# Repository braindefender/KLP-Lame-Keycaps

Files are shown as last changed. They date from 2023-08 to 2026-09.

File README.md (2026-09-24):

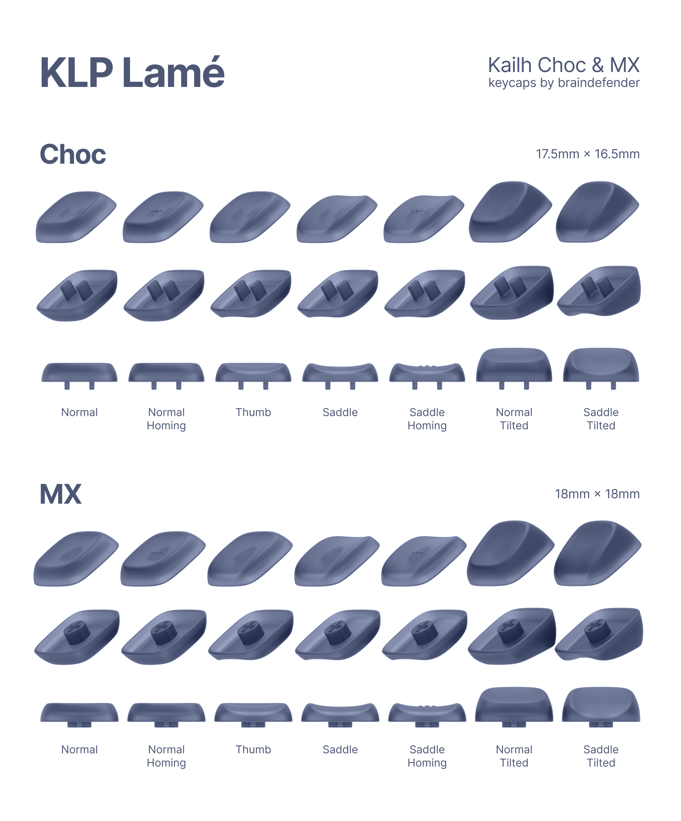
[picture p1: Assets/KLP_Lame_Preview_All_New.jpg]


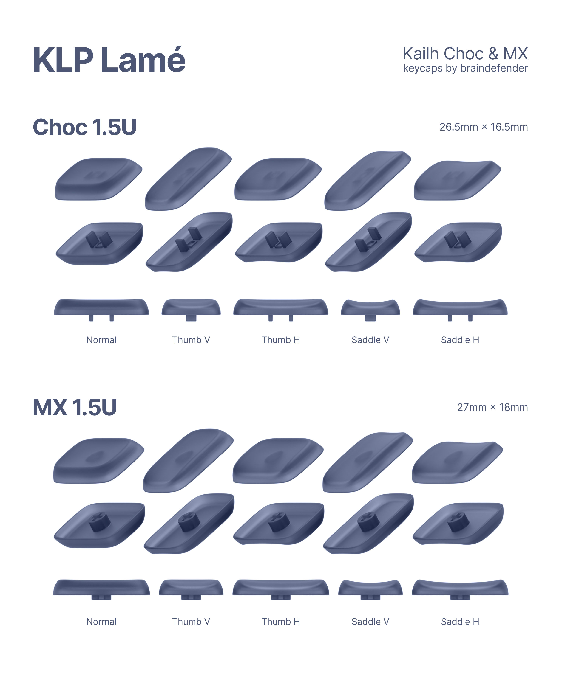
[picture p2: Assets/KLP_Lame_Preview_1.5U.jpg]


# KLP Lamé — Kailh Choc & MX Keycaps

Sculpted and curved keycaps for Kailh Choc and MX switches. Here is a project structure:

| Folder | Description |
| :--- | :--- |
| **Assets** | Various images and actual photos of keycaps |
| **Blender** | Blender files for preview image render |
| **Fusion 360** | Source files for [Autodesk Fusion 360](https://www.autodesk.com/products/fusion-360/overview) |
| **Production** | Combined STL 3D models suitable for 3D-Printing services (like [JLC3DP](https://jlc3dp.com))  |
| **STEP** | 3D models in STEP format for any CAD or Slicer software |
| **STL** | 3D models in STL format for any CAD or Slicer software |

> `STEP` and `STL` folders contain all combinations of Choc/MX Stem + Choc/MX Size.
>
> There is also `90 deg Rotated` variants for Choc Stem.

There are currently 7 variants of 1U keycaps:
| Variant | Description |
| :--- | :--- |
| **Normal** | Just a flat keycap profile with a small recess, that is soothing for fingers |
| **Normal Tilted** | Same as Normal, but top profile has a 15° tilt and 0.5mm upward height compensation |
| **Normal Homing** | Has three little bumps that is useful to determine home positions |
| **Thumb** | Same as Normal, but top profile has a cut along down side |
| **Saddle** | Same as Thumb, but top profile has two symmetrical cuts |
| **Saddle Tilted** | Tilted version of Saddle. Same 15° and height compensation |
| **Saddle Homing** | Has three little bumps that is useful to determine home positions |

And also 5 variants of 1.5U keycaps:
| Variant | Description |
| :--- | :--- |
| **Normal** | Just a flat keycap profile with a small recess, that is soothing for fingers |
| **Thumb H**  | 1.5U variant of Thumb. Horizontal |
| **Thumb V**  | 1.5U variant of Thumb. Vertical (stem is rotated) |
| **Saddle H** | 1.5U variant of Saddle. Horizontal |
| **Saddle V** | 1.5U variant of Saddle. Vertical (stem is rotated) |

## What keycaps do I need for my keyboard?

First, you should choose Choc/MX stem (depends of your switches)<br>
Second, choose Choc/MX size that is suitable for your keyboard.<br>
Then, pick what keycap variants you want for your columns/rows/thumbs. It depends entirely of your choice.

For corne-like keyboards with 36-keys I use:

| Amount | Kind | Purpose |
| -----: | :--- | :--- |
| 20 | Saddle Tilted | For top and bottom rows |
| 16 | Saddle | For home row + 6 for thumbs |

or

| Amount | Kind | Purpose |
| -----: | :--- | :--- |
| 20 | Normal Tilted | For top and bottom rows |
| 10 | Normal | For home row |
| 6 | Thumb | For thumbs |

## Where to buy?

> Use middle click or tap & hold to open in new tab

<a href="https://aliexpress.ru/wholesale?SearchText=klp+lame">
  aliexpress.ru
</a>
<a href="https://ergosplits.ru/item/219">
  ergosplits.ru
</a>
<a href="https://fkcaps.com/collections/klp-lame">
  fkcaps.com
</a>
<a href="https://holykeebs.com/products/klp-lame-keycaps">
  holykeebs.com
</a>
<a href="https://www.keebart.com/products/klp-lame-keycaps">
  keebart.com
</a>
<a href="https://keeb.supply/search?q=Lame">
  keeb.supply
</a>
<a href="https://keycapsss.com/KLP-Lame-Ergonomic-Keycaps-Choc/KC10269">
  keycapsss.com
</a>
<a href="https://typeractive.xyz/products/klp-lame-sculpted-keycaps">
  typeractive.xyz
</a>
<a href="https://shop.yushakobo.jp/search?q=Lame">
  yushakobo.jp
</a>
<a href="https://yuzukeycaps.com">
  yuzukeycaps.com
</a>

## How to print?

It is best to position the model more vertically to avoid tactile layer-to-layer bumps. Personally, I use 45° or 75° angle, but it's up to you.

`Production` folder contains files that you can use in any 3D-printing service like [JLC3DP](https://jlc3dp.com) or [PCBWay](https://www.pcbway.com/rapid-prototyping/3d-printing/). You can download them directly using links below:

### Normal

| File | Choc Stem + Choc Size | Choc Stem + MX Size | MX Stem + MX Size | MX Stem + Choc Size | Kinds |
| :--- | :--- | :--- | :--- | :--- | --- |
| Normal Part 1 | [Download][normal-part-1-choc] | [Download][normal-part-1-choc-mx] | [Download][normal-part-1-mx] | [Download][normal-part-1-mx-choc] | - 6 × Normal Tilted<br/>- 3 × Normal |
| Normal Part 2 | [Download][normal-part-2-choc] | [Download][normal-part-2-choc-mx] | [Download][normal-part-2-mx] | [Download][normal-part-2-mx-choc] | - 4 × Normal Tilted<br/>- 3 × Thumb<br/>- 1 × Normal Homing<br/>- 1 × Normal |
| Normal Part 3 | [Download][normal-part-3-choc] | [Download][normal-part-3-choc-mx] | [Download][normal-part-3-mx] | [Download][normal-part-3-mx-choc] | - 9 × Normal Tilted |

### Saddle

| File | Choc Stem + Choc Size | Choc Stem + MX Size | MX Stem + MX Size | MX Stem + Choc Size | Kinds |
| :--- | :--- | :--- | :--- | :--- | --- |
| Saddle Part 1 | [Download][saddle-part-1-choc] | [Download][saddle-part-1-choc-mx] | [Download][saddle-part-1-mx] | [Download][saddle-part-1-mx-choc] | - 6 × Saddle Tilted<br/>- 3 × Saddle |
| Saddle Part 2 | [Download][saddle-part-2-choc] | [Download][saddle-part-2-choc-mx] | [Download][saddle-part-2-mx] | [Download][saddle-part-2-mx-choc] | - 4 × Saddle Tilted<br/>- 4 × Saddle<br/>- 1 × Saddle Homing |
| Saddle Part 3 | [Download][saddle-part-3-choc] | [Download][saddle-part-3-choc-mx] | [Download][saddle-part-3-mx] | [Download][saddle-part-3-mx-choc] | - 9 × Saddle Tilted |

### Thumbs

| File | Choc Stem + Choc Size | Choc Stem + MX Size | MX Stem + MX Size | MX Stem + Choc Size | Kinds |
| :----- | :--- | :--- | :--- | :--- | --- |
| Thumbs | [Download][thumbs-part-1-choc] | [Download][thumbs-part-1-choc-mx] | [Download][thumbs-part-1-mx] | [Download][thumbs-part-1-mx-choc] | - 9 × Thumb |

[normal-part-1-choc]: ./Production/Choc%20Stem%20%2B%20Choc%20Size/Choc_Stem_Choc_Size_Normal_Part_1.zip
[normal-part-2-choc]: ./Production/Choc%20Stem%20%2B%20Choc%20Size/Choc_Stem_Choc_Size_Normal_Part_2.zip
[normal-part-3-choc]: ./Production/Choc%20Stem%20%2B%20Choc%20Size/Choc_Stem_Choc_Size_Normal_Part_3.zip

[normal-part-1-choc-mx]: ./Production/Choc%20Stem%20%2B%20MX%20Size/Choc_Stem_MX_Size_Normal_Part_1.zip
[normal-part-2-choc-mx]: ./Production/Choc%20Stem%20%2B%20MX%20Size/Choc_Stem_MX_Size_Normal_Part_2.zip
[normal-part-3-choc-mx]: ./Production/Choc%20Stem%20%2B%20MX%20Size/Choc_Stem_MX_Size_Normal_Part_3.zip

[normal-part-1-mx]: ./Production/MX%20Stem%20%2B%20MX%20Size/MX_Stem_MX_Size_Normal_Part_1.zip
[normal-part-2-mx]: ./Production/MX%20Stem%20%2B%20MX%20Size/MX_Stem_MX_Size_Normal_Part_2.zip
[normal-part-3-mx]: ./Production/MX%20Stem%20%2B%20MX%20Size/MX_Stem_MX_Size_Normal_Part_3.zip

[normal-part-1-mx-choc]: ./Production/MX%20Stem%20%2B%20Choc%20Size/MX_Stem_Choc_Size_Normal_Part_1.zip
[normal-part-2-mx-choc]: ./Production/MX%20Stem%20%2B%20Choc%20Size/MX_Stem_Choc_Size_Normal_Part_2.zip
[normal-part-3-mx-choc]: ./Production/MX%20Stem%20%2B%20Choc%20Size/MX_Stem_Choc_Size_Normal_Part_3.zip

[saddle-part-1-choc]: ./Production/Choc%20Stem%20%2B%20Choc%20Size/Choc_Stem_Choc_Size_Saddle_Part_1.zip
[saddle-part-2-choc]: ./Production/Choc%20Stem%20%2B%20Choc%20Size/Choc_Stem_Choc_Size_Saddle_Part_2.zip
[saddle-part-3-choc]: ./Production/Choc%20Stem%20%2B%20Choc%20Size/Choc_Stem_Choc_Size_Saddle_Part_3.zip

[saddle-part-1-choc-mx]: ./Production/Choc%20Stem%20%2B%20MX%20Size/Choc_Stem_MX_Size_Saddle_Part_1.zip
[saddle-part-2-choc-mx]: ./Production/Choc%20Stem%20%2B%20MX%20Size/Choc_Stem_MX_Size_Saddle_Part_2.zip
[saddle-part-3-choc-mx]: ./Production/Choc%20Stem%20%2B%20MX%20Size/Choc_Stem_MX_Size_Saddle_Part_3.zip

[saddle-part-1-mx]: ./Production/MX%20Stem%20%2B%20MX%20Size/MX_Stem_MX_Size_Saddle_Part_1.zip
[saddle-part-2-mx]: ./Production/MX%20Stem%20%2B%20MX%20Size/MX_Stem_MX_Size_Saddle_Part_2.zip
[saddle-part-3-mx]: ./Production/MX%20Stem%20%2B%20MX%20Size/MX_Stem_MX_Size_Saddle_Part_3.zip

[saddle-part-1-mx-choc]: ./Production/MX%20Stem%20%2B%20Choc%20Size/MX_Stem_Choc_Size_Saddle_Part_1.zip
[saddle-part-2-mx-choc]: ./Production/MX%20Stem%20%2B%20Choc%20Size/MX_Stem_Choc_Size_Saddle_Part_2.zip
[saddle-part-3-mx-choc]: ./Production/MX%20Stem%20%2B%20Choc%20Size/MX_Stem_Choc_Size_Saddle_Part_3.zip

[thumbs-part-1-choc]: ./Production/Choc%20Stem%20%2B%20Choc%20Size/Choc_Stem_Choc_Size_Thumbs.zip
[thumbs-part-1-choc-mx]: ./Production/Choc%20Stem%20%2B%20MX%20Size/Choc_Stem_MX_Size_Thumbs.zip
[thumbs-part-1-mx]: ./Production/MX%20Stem%20%2B%20MX%20Size/MX_Stem_MX_Size_Thumbs.zip
[thumbs-part-1-mx-choc]: ./Production/MX%20Stem%20%2B%20Choc%20Size/MX_Stem_Choc_Size_Thumbs.zip

## Can I use these models for a production and sale?

Yes. But you must leave a mention of this repository/author to end users.

## Can I modify, fork, post (or whatever) these models?

Yes. Rules are the same. Give a credit to the author.

## Changelog
v1.5u
- [Models] Well, 1.5U keycap sizes for both Choc/MX Stem + Choc/MX Size.

v1.4
- [Models] Updated Choc Stem to be compatible with silent choc switches.
- [Project] Added Choc_Stem + MX_Size 90° rotated variants (both STL and STEP).
- [Production] Increased surface area of connected parts to improve print stability.

v1.3
- [Models] Added mix and match variants for Choc/MX Stem + Choc/MX Size.
- [Project] Updated folder structure to accomodate mix and match variants.
- [Project] Removed Lychee (legacy) project files.

v1.2
- [Models] Added Choc version with 90° rotated stem.

v1.1

- [Models] Added chamfers along inner bottom line (1.2mm for Choc and 1.4mm for MX).
- [Project] Added separate Fusion project files.
- [Project] Updated Images & Photos.

> Now the models are also suitable for FDM 3D Printers. But I still recommend using SLA for better quality.

v1.0

- Initial Release.

## Images & Photos

### From various awesome people

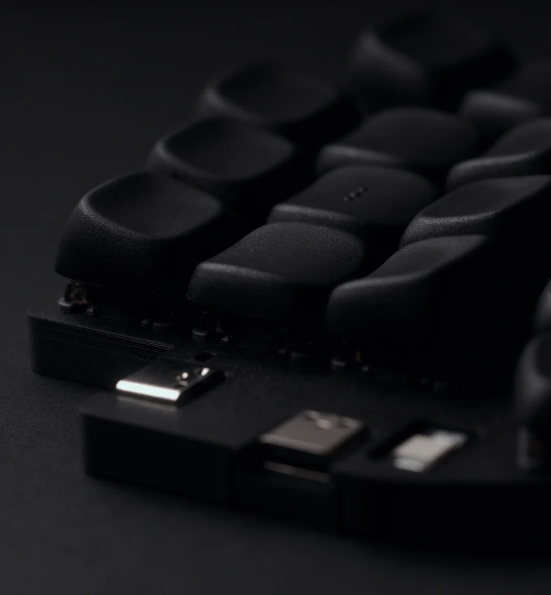
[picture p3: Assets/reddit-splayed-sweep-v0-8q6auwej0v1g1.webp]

By [u/unspecified-work](https://www.reddit.com/user/unspecified-work/) from [Reddit](https://www.reddit.com/r/ErgoMechKeyboards/comments/1oznwnv/splayed_sweep/)

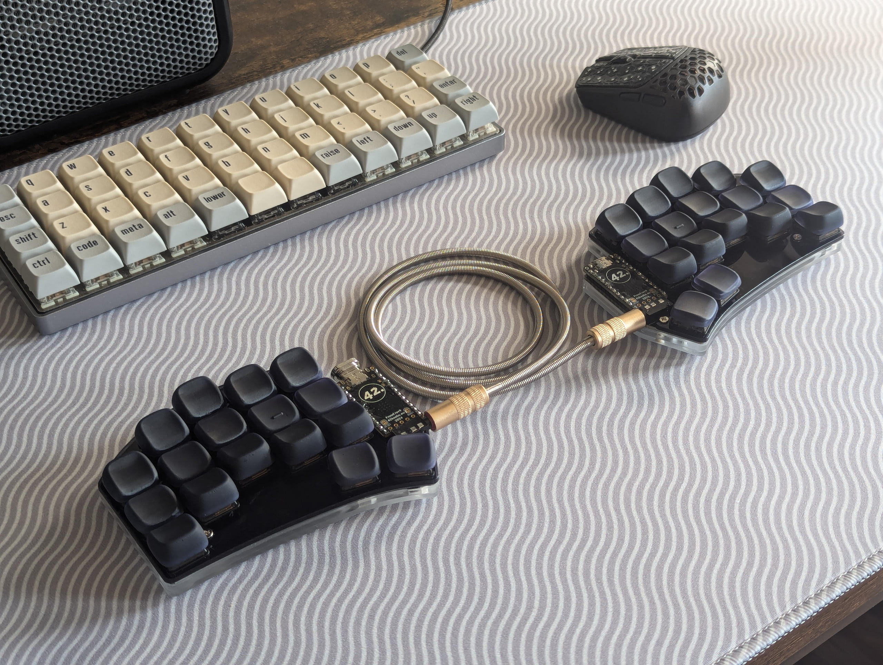
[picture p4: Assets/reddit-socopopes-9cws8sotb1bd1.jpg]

By [u/socopopes](https://www.reddit.com/user/socopopes/) from [Reddit](https://www.reddit.com/r/ErgoMechKeyboards/comments/1dx9d7j/down_14_more_keys_only_34_more_to_go/)

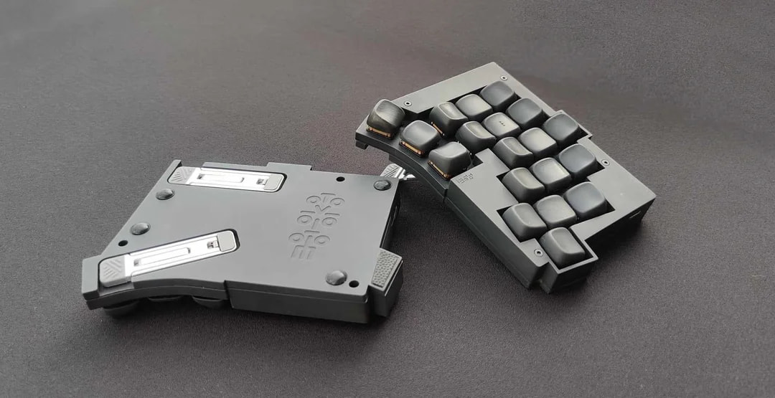
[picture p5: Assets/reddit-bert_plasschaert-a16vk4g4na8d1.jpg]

By [u/bert_plasschaert](https://www.reddit.com/user/bert_plasschaert/) from [Reddit](https://www.reddit.com/r/ErgoMechKeyboards/comments/1dmirsg/totem_tenting_bottom_plate/)

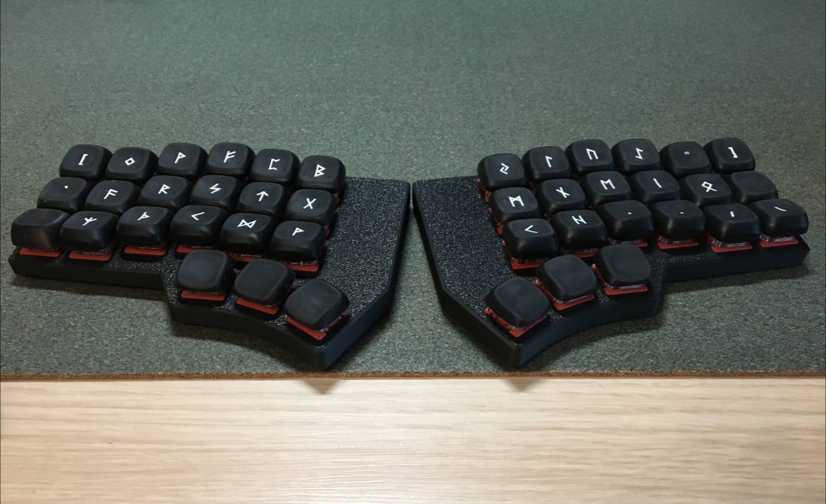
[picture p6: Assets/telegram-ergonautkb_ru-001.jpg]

By [proostas](https://t.me/proostas) from [Ergonaut Keyboards Ru](https://t.me/ergonautkb_ru)

### Original photos

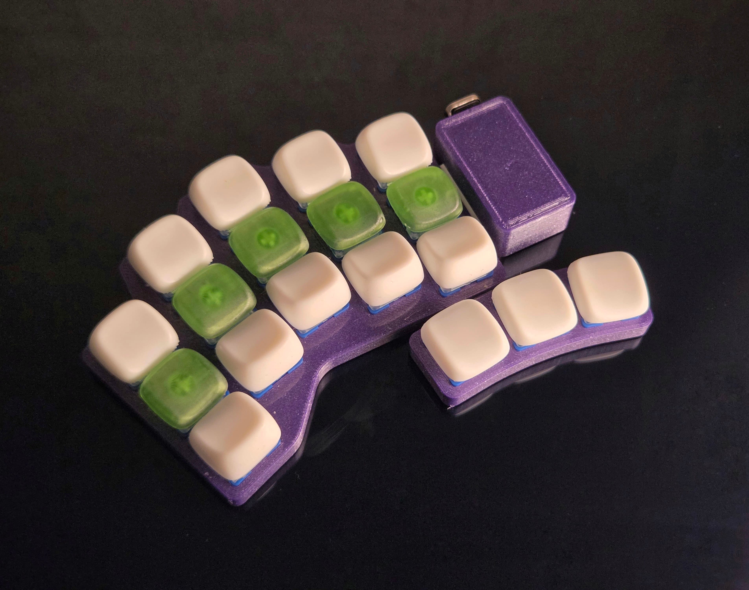
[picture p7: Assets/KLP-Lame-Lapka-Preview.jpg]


> The keyboard is my side-project [Lapka](https://github.com/braindefender/lapka)

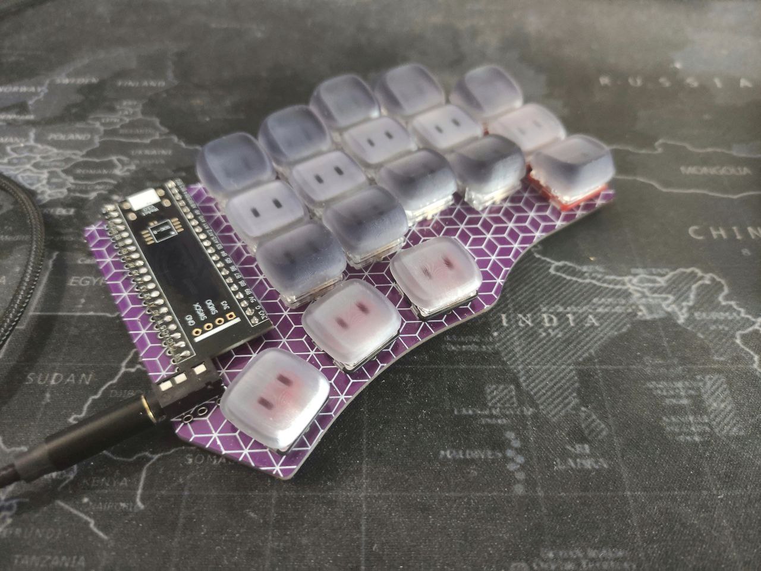
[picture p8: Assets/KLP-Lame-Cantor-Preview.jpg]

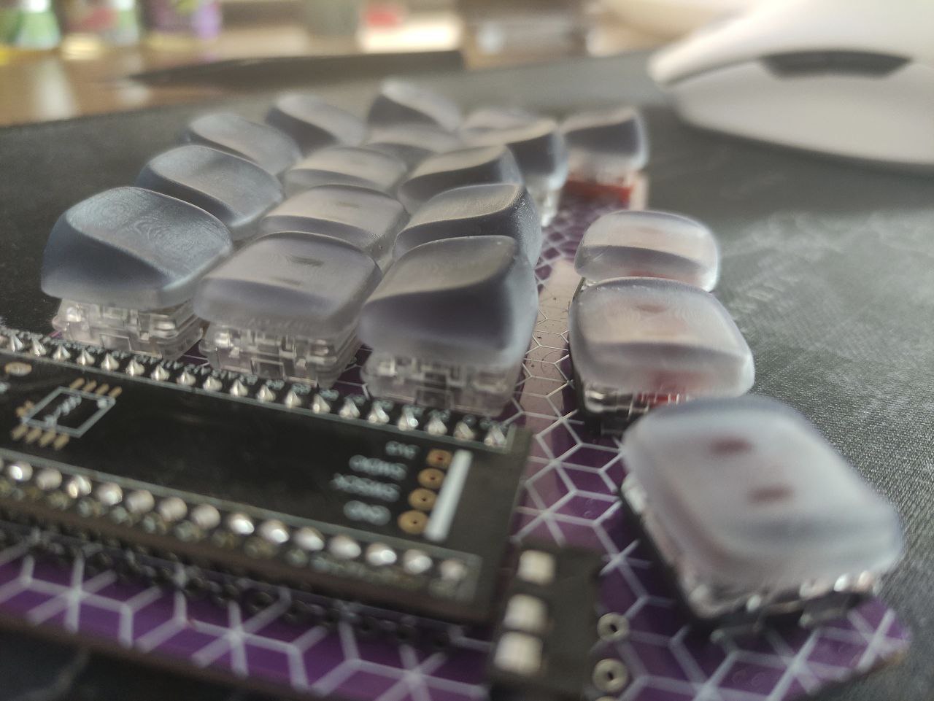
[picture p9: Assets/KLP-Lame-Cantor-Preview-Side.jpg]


> The keyboard is [Cantor Remix](https://github.com/nilokr/cantor-remix)

## Contacts

@braindefender (preferably, [Telegram](t.me/braindefender), but also [GMail](mailto:braindefender@gmail.com) and [Reddit](https://www.reddit.com/user/braindefender/))

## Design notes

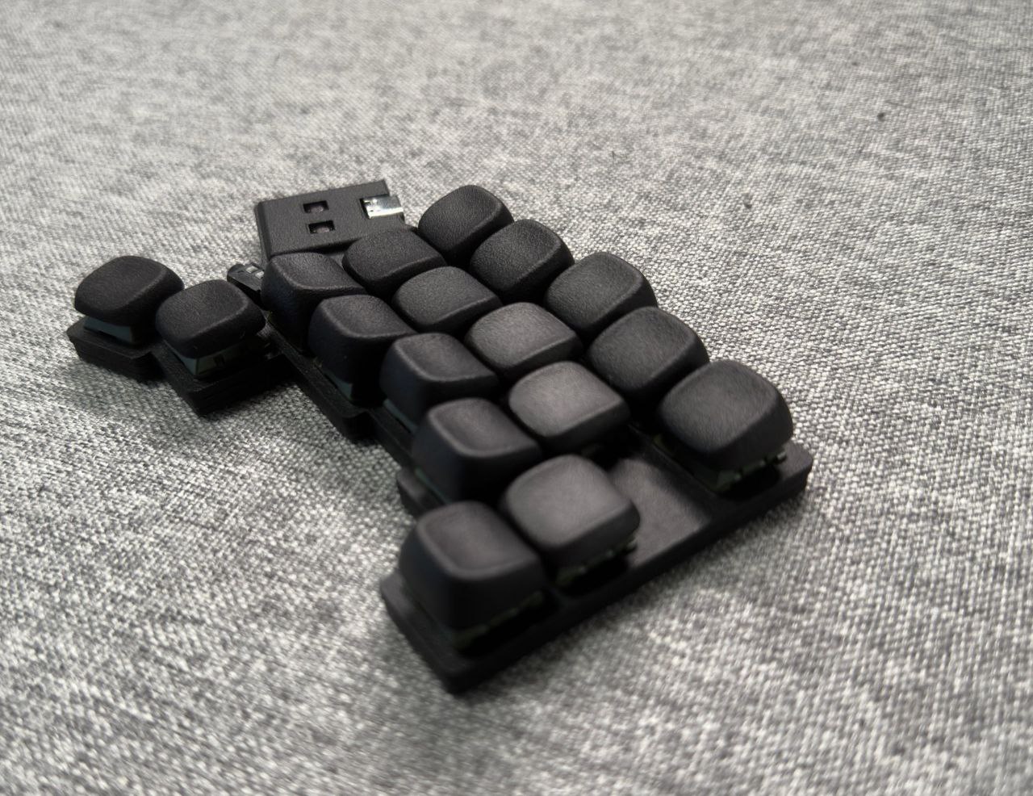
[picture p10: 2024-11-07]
Assets/unknown-8j3bn7a913sf4.jpg

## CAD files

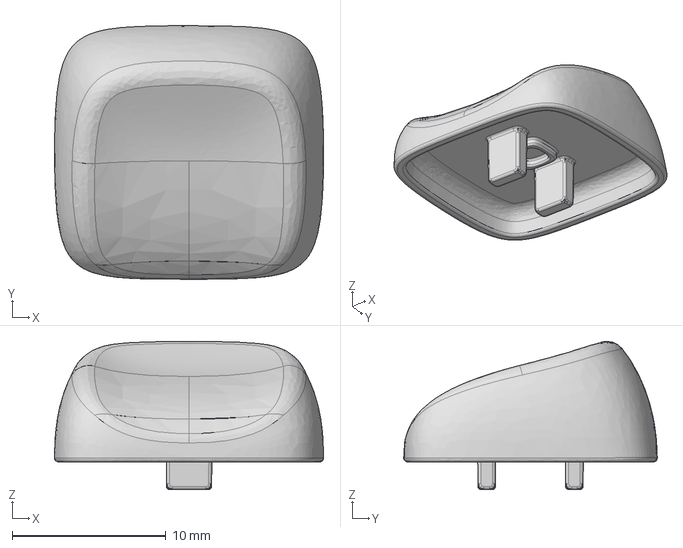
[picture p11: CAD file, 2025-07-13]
STEP/Choc Stem + Choc Size/90 deg Rotated/Choc_Stem_Choc_Size_Saddle_Tilted_90deg.step
17.5 x 16.5 x 9.63 mm

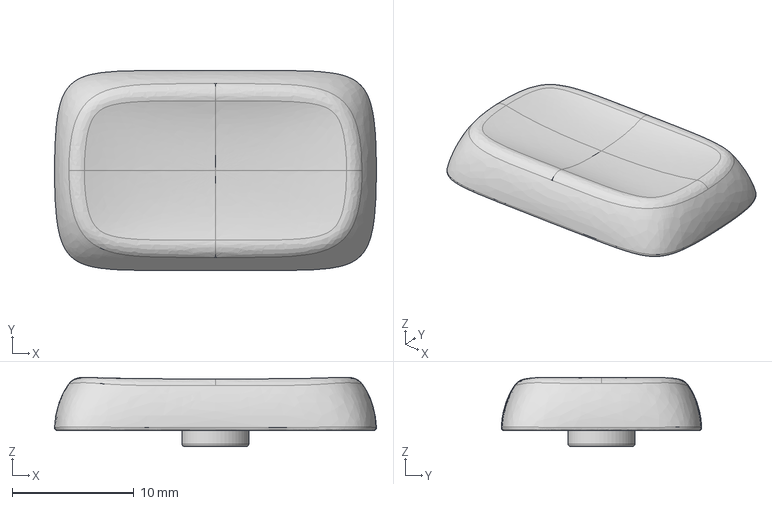
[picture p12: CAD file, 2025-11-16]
STEP/Choc Stem + Choc Size/Choc_Stem_Choc_Size_1.5U_Normal.step
26.5 x 16.5 x 5.68 mm

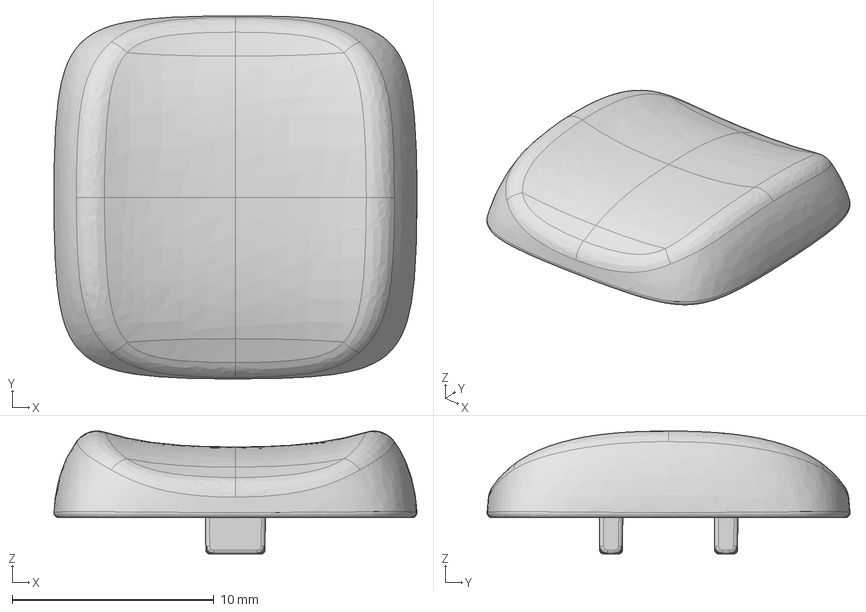
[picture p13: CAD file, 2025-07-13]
STEP/Choc Stem + MX Size/90 deg Rotated/Choc_Stem_MX_Size_Saddle_90deg.step
18.0 x 18.0 x 6.09 mm

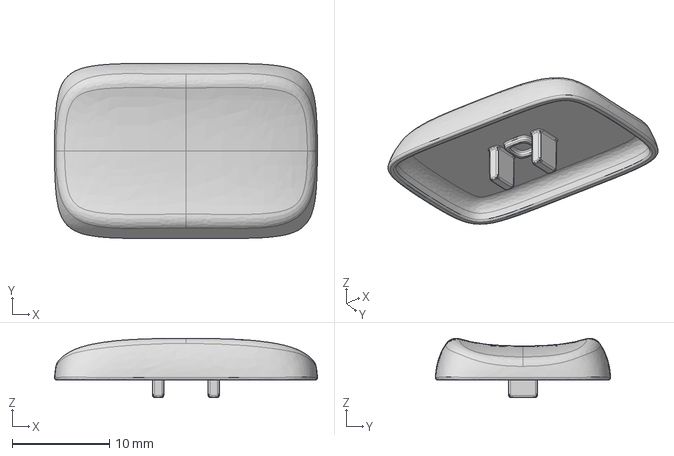
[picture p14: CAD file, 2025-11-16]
STEP/Choc Stem + MX Size/Choc_Stem_MX_Size_1.5U_Saddle_V.step
27.0 x 18.0 x 6.09 mm

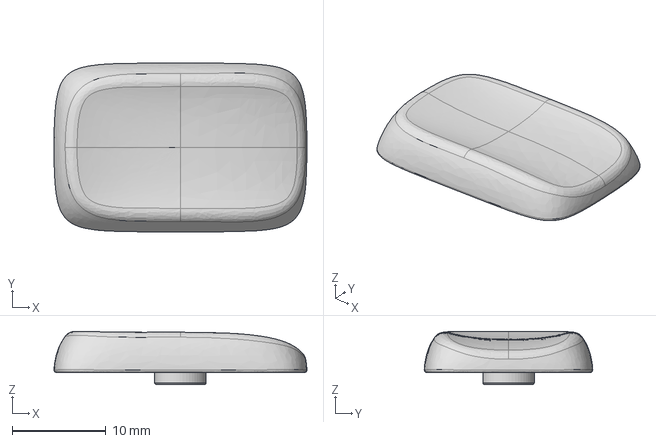
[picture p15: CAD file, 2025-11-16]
STEP/MX Stem + MX Size/MX_Stem_MX_Size_1.5U_Thumb_V.step
27.0 x 18.0 x 5.68 mm

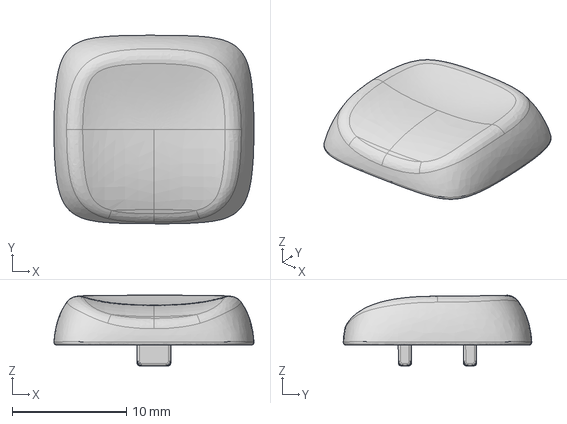
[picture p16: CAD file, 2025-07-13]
STEP/Choc Stem + Choc Size/90 deg Rotated/Choc_Stem_Choc_Size_Thumb_90deg.step
17.5 x 16.5 x 6.17 mm

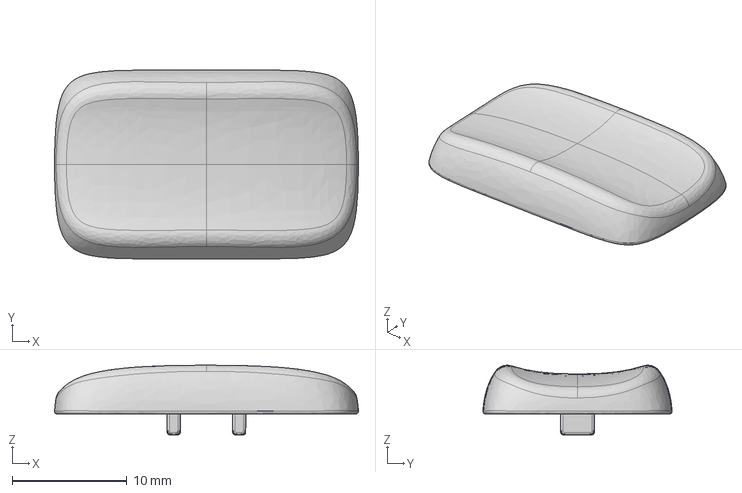
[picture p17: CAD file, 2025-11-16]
STEP/Choc Stem + Choc Size/Choc_Stem_Choc_Size_1.5U_Saddle_V.step
26.5 x 16.5 x 6.07 mm

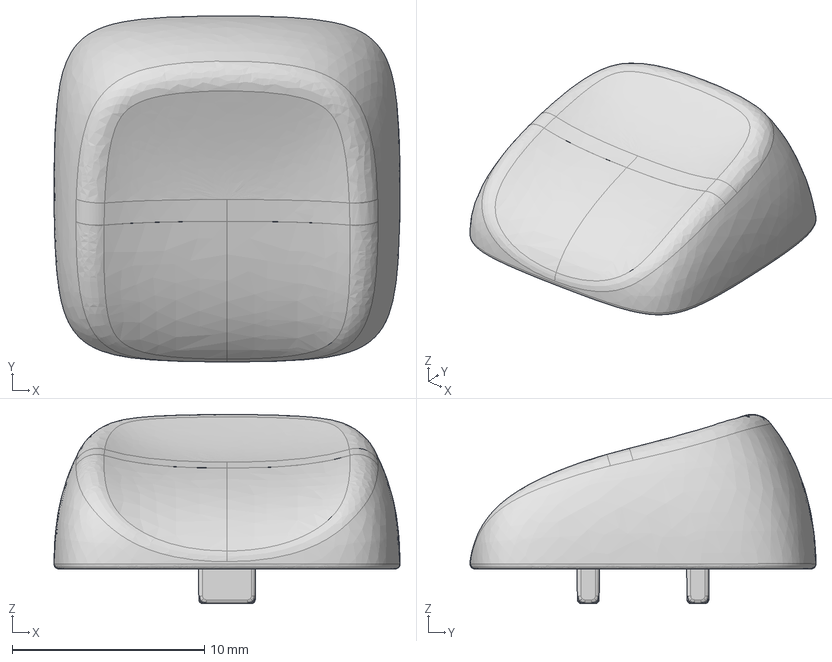
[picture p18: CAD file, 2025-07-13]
STEP/Choc Stem + MX Size/90 deg Rotated/Choc_Stem_MX_Size_Saddle_Tilted_90deg.step
18.0 x 18.0 x 9.84 mm

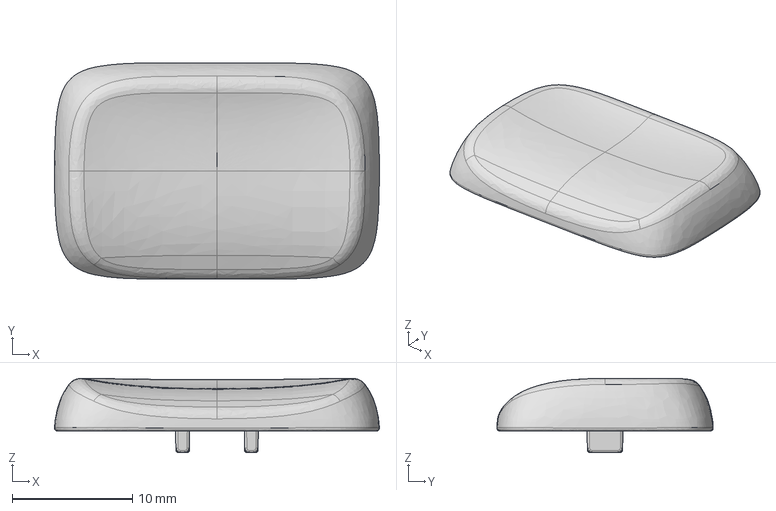
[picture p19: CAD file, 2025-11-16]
STEP/Choc Stem + MX Size/Choc_Stem_MX_Size_1.5U_Thumb_H.step
27.0 x 18.0 x 6.18 mm

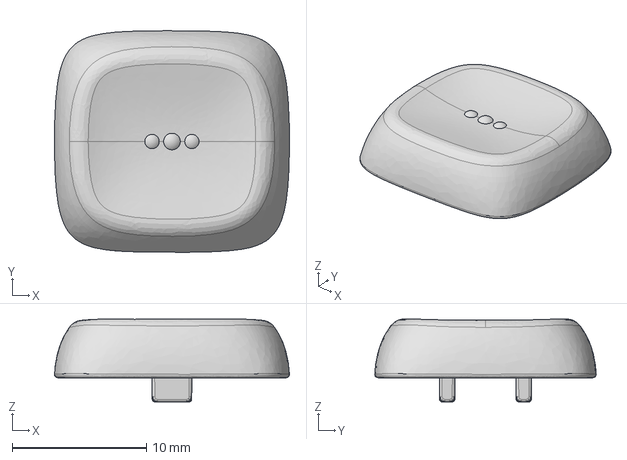
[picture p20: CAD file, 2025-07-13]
STEP/Choc Stem + Choc Size/90 deg Rotated/Choc_Stem_Choc_Size_Normal_Homing_90deg.step
17.5 x 16.5 x 6.17 mm

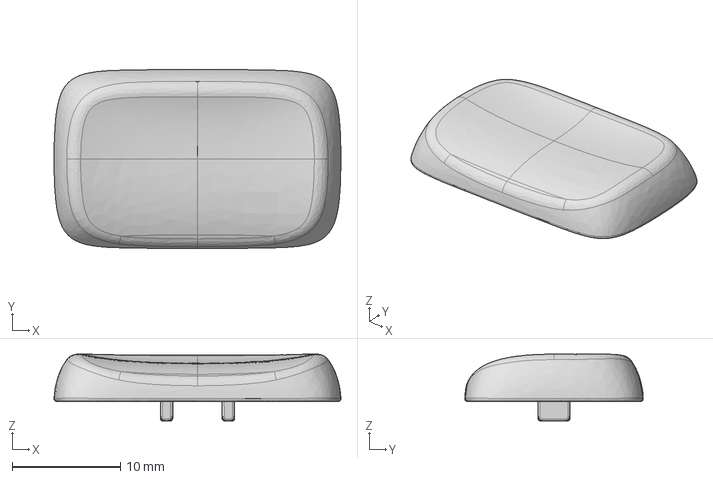
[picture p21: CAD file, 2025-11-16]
STEP/Choc Stem + Choc Size/Choc_Stem_Choc_Size_1.5U_Thumb_H.step
26.5 x 16.5 x 6.18 mm

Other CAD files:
STEP/MX Stem + Choc Size/MX_Stem_Choc_Size_1.5U_Saddle_H.step
STL/Choc/Combined/KLP-Lame-Saddle-6ST-3S-Combined.stl
STEP/MX Stem + Choc Size/MX_Stem_Choc_Size_1.5U_Thumb_V.step
STEP/MX Stem + MX Size/MX_Stem_MX_Size_1.5U_Normal.step
STL/Choc/Combined/KLP-Lame-Normal-6NT-3N-Combined.stl
STEP/Choc Stem + MX Size/90 deg Rotated/Choc_Stem_MX_Size_Normal_Tilted_90deg.step
STEP/Choc Stem + MX Size/Choc_Stem_MX_Size_1.5U_Thumb_V.step
Fusion/Choc Rotated/[Choc] Normal 90deg.f3z
Fusion/Choc Rotated/[Choc] Normal Homing 90deg.f3z
Fusion/Choc Rotated/[Choc] Normal Tilted 90deg.f3z
Fusion/Choc Rotated/[Choc] Saddle 90deg.f3z
Fusion/Choc Rotated/[Choc] Saddle Homing 90deg.f3z
Fusion/Choc Rotated/[Choc] Saddle Tilted 90deg.f3z
Fusion/Choc Rotated/[Choc] Thumb 90deg.f3z
Fusion/Choc/[Choc] Normal Homing.f3z
Fusion/Choc/[Choc] Normal Tilted.f3z
Fusion/Choc/[Choc] Normal.f3z
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

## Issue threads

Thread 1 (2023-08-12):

1.5U?

b166ar, 2023-08-12:
Any plans to make 1.5U thumb? For Chocofi and similar keyboards.

braindefender, 2023-08-13:
No, I do not plan to add 1.5U or other sizes. Perhaps, someone will make PR with this.

KLingO-MS, 2024-04-02:
Could You please create caps for index center column that will be tilted to the side (of course corner ones then would be tilted in 2 directions)

smallwat3r, 2024-05-18:
@b166ar I've found a MX version of a 1.5U thumb key on [this](https://github.com/vvhg1/clp-keycaps/blob/main/stl/CLP_Tilt7_1_5u%20v13.stl) repo. The keys have been inspired by the KLP Lame, so it fits quite well the design.

Because I'm using choc keycaps and not MX, I modified it so it has a choc plug, you can find the STL attached.

[CLP_Tilt7_1_5u_choc.stl.zip](https://github.com/braindefender/KLP-Lame-Keycaps/files/15366275/CLP_Tilt7_1_5u_choc.stl.zip)

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

Closed 2024-11-06.

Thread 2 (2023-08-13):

Saddle homing stl

safstromo, 2023-08-13:
Can you make a Saddle homing stl for us that cant use Fusion please :)

braindefender, 2023-08-13:
You are welcome.

safstromo, 2023-08-13:
Thanks :heart:

Closed 2023-08-13.

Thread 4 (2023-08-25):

STL for thumb choc

KLingO-MS, 2023-08-25:
Hello
STL file for thumb version in Choc folder is actually same as normal homing.

braindefender, 2023-08-26:
Thanks. It was introduced with MX update and error also present in render. Fixed.

KLingO-MS, 2023-08-26:
Thank You for quick fix.

Closed 2023-08-26.

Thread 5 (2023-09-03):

"combined" stl files are not being accepted by Jlcpcb as witten in README

DeBasti, 2023-09-03:
I tried to order the choc stl saddle combined https://github.com/braindefender/KLP-Lame-Keycaps/blob/master/STL/Choc/Combined/KLP-Lame-36-keys-Saddle-Combined.stl from jlcpcb and got the response that every stl file should only contain one part. I think the issue is that the keycaps are not connected thus being seen as different parts by jlcpcb.

Full response from jlcpcb:
Dear Sir/Madam, multiple parts (shells) were detected in your file, sorry to tell you that each file could only support 1 part (shell) for printing, please kindly separate the multiple shells into single files to place the order separately. Thanks !

braindefender, 2023-09-04:
Yes, I already addressed this issue and updated files. Also, there are limits to the width/height/file_size of the models, so I split combined parts into 18 caps per file. See this [commit](https://github.com/braindefender/KLP-Lame-Keycaps/commit/e47f24cc744540d3f8e0e0966f2e87a1adeed80d)

DeBasti, 2023-09-04:
Great! Thank you :)

braindefender, 2023-09-04:
Seems like JLC want only 10 caps per file. Working on it...

braindefender, 2023-09-04:
Now it is correct, I think

Closed 2023-09-04.

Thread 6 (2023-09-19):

Increase home keys bumps

mike1808, 2023-09-19:
The current version has a very small bumps to indicate home keys. When printed with 50 micron mSLA printer those nibs are very hard to feel.
I tried increasing the ball diameter to 2mm and only having two of those and it feels good to use.
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

I can provide pictures of printed caps if needed.

ald0o, 2023-09-27:
I printed them in FDM (TPU 95A) "super quality" (0.12 mm layers... so that would be 120 μm, comparing apples to apples!), and the bumps are also completely unnoticeable, as expected.

I am aware these keycaps were not meant for FDM, but except the issue with homing bumps, they are actually quite fine, so it would definitely be worth it to fix this little issue.

mike1808, 2023-09-28:
I tried making a photo but not sure you can see it. On the left is my modified version, on the right is the original version
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

braindefender, 2023-10-27:
I'll fix it in the next update

braindefender, 2023-10-29:
You are welcome. Check out last commits and updates.

smallwat3r, 2024-04-29:
@mike1808, I quite like your version of the home keys with the increased two dots. Any chance you could share an STL file? Thanks!

Closed 2023-10-29.

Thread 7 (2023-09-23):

How to make the key caps transparent

sedghi, 2023-09-23:
I'm new to the world of custom ergo mech keyboards. I also know nothing about 3D printing.

My question is if i want to order on the manufacturer can i choose the transparent color?  Is there a technical term for it? And whether there is anything i should note when I'm choosing manufacturer

Thanks!

mike1808, 2023-09-25:
You have to choose a transparent material. From what I can see PCBway has an option to choose a transparent resin. However, don't expect it to be perfectly transparent since getting 100% is a challenging in 3d printing.

sedghi, 2023-09-25:
Thanks @mike1808
I have heard it should be biocompatible resin since you touch it multiple hours per day, Do you have any comment on that too?

mike1808, 2023-09-25:
@sedghi cured resin is mostly inert.
Here is  the video with how to order a printed part from PCBway in clear resin https://www.youtube.com/watch?v=SsvZZx0RXUY

sedghi, 2023-09-25:
Thanks a lot!

Closed 2023-10-27.

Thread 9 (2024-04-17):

MX STLs not able to be opened in Cura and Prusa

stevenschmutz, 2024-04-17:
Have downloaded all the MX  STLs and they are not able to be opened in Cura or PrusaSlicer.

braindefender, 2024-04-18:
I don't know why this is happening. Someone on Reddit also has this problem.
But I don't. Just downloaded all MX models and they can be opened in PrusaSlicer (2.7.2)

stevenschmutz, 2024-04-19:
Problem solved!  After cloning the repo to my local drive, I can use both Prusa and Cura to slice the STLs.

Seems that downloading the individual files from the GitHub repo was the probelm.

Closed 2024-04-19.

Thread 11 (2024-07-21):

Гдпнззкодевврщгууе6зхлачвагщщпасолщнвол4344343ликш 45444444444 4

prototype-2-0, 2024-07-21:

braindefender, 2024-07-24:
кошка прыгнула на клаву и открыла GitHub Issue? что-то слабо верится...

Closed 2024-07-24.

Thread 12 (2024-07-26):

Choc size with MX stem

okkdev, 2024-07-26:
I'd love a version of the caps with the 17.5mm × 16.5mm choc size but an MX stem.

I prefer the feel of the choc v2 and gateron low profile switches which both use MX stems. Most ergo keyboards are designed with choc v1 switches in mind. That led to me modifying the pcb switch footprint to allow for the other switches, but adjusting the spacing between the switches would require significant redesign of the board.
Making a choc sized MX stem cap would be the perfect solution. :)

Closed 2025-05-10.

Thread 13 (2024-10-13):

Do these fit with choc spacing?

sljdhl, 2024-10-13:
Im about to build a choc spaced corne and wondering if these would fit, or if it needs to be mx spaced

zawnk, 2024-10-19:
I just printed them and put them on my corax which is choc spaced and they fit just fine. So I'd argue that they fit :)

braindefender, 2024-10-21:
> if these would fit, or if it needs to be mx spaced

The description literally states that there CHOC version and MX version for different switch spacings.

BenRoe, 2024-10-24:
The KLP keycaps have the following dimensions:
W: 17.5mm / H: 16.5mm

Choc keycaps have:
W: 17.7mm / H: 16.7mm

Conclusion KLP Lame keycaps fit with a choc spacing layout.

Closed 2024-10-21.

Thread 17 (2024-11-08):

Print settings

sadtab, 2024-11-08:
I'm trying to print these jems in PETG, I cant really find the best angle to print them, could you also include a cura or pusa project file with the optimal angle to print them, I'm wondering how you can possible print the MX version with no support

braindefender, 2024-11-09:
I don't have any particular project files for FDM, but I think supports are mandatory.
And optimal angle for Choc and MX differs, I suppose. Will try to print some MX's later

sadtab, 2024-11-11:
I appreciate if you could post some screenshots, I just can't get that perfect angle

braindefender, 2024-11-15:
But I don't think that is possible to print them entirely without supports...

braindefender, 2024-12-09:
@sadtab

UPD: that is possible. Need post-processing, but MX socket is almost perfect and without any supports.

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

[KLP Lame FDM Test.zip](https://github.com/user-attachments/files/18056353/KLP.Lame.FDM.Test.zip)

Closed 2024-11-15.

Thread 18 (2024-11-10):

Wrong file in Blender folder

eemrull, 2024-11-10:
/Blender/MX/KLP-Saddle-4xSaddle_Tilted-4xSaddle-1xSaddle_Homing-Combined.7z

contains .stl not .blend

braindefender, 2024-11-10:
Thanks, fixed!

Closed 2024-11-10.

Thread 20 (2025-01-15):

Would you upload them as step file?

Finnitio, 2025-01-15:
Hello,

I would apprciate if you could uploaf the keycaps as step file?

Kind regards

braindefender, 2025-01-17:
Hello. You can download STL's and convert them to STEP via online tools.

Finnitio, 2025-01-17:
Hey, that is true and I am aware of that possibility. The reason rather is, that stl is a mesh and a conversion to step will be a representation of that mesh.

Step files in that regard are not a triangulation thus radiuses etc are no approximation.

braindefender, 2025-01-18:
Thanks. I didn't know that. You can find STEP files in master branch now

Closed 2025-01-18.

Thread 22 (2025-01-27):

Potential issues with connectors in combined .stl files and SLS printing

alexyung, 2025-01-27:
I want to preface this by saying that I have no experience with 3D printing and modeling for 3D printing, so I'm not sure if this necessarily an issue with the model or just my choices in how I had the keycaps printed.

I recently had the combined files for the Normal MX version of these keycaps printed with SLS from JLCPCB. Unfortunately, the keycaps arrived mostly broken off their connectors already and with some pieces missing - I had 3 extra tilted caps and missing 3 thumb caps for one of the Normal Part 2 MX sets. I talked to JLC support, and got this response:

> As per your design, the wall thickness is only around 1.5mm, which will be prone to breakage and result in small parts separated so easily leads to a mix-up issue.
> To serve you better, for future orders with such kind of model, would you please add some unique letters or numbers on the keycaps or may be at the backside? Otherwise you may increase the wall thickness of the connection area to be more than 3.0mm.
> Concerning the current parts, we afraid there were some keycaps got missing. When we arranged reproduction of them, they somehow got mixed up so wrong keycaps being reprinted.

It seems they complained that the connectors were too small/weak and the caps broke off during processing, which caused the mixup.

Is it possible to make the connectors for the combined .stl's thicker/stronger to stop mixups like these from happening again? Otherwise, maybe it should be made clear what type of printing would be ideal for these keycaps?

braindefender, 2025-01-27:
Hi. Thanks for reporting this issue. I've never printed them in SLS so maybe the issue is there. I will look onto this.

braindefender, 2025-07-13:
I increased surface area of connector parts. Now they should print more stable.

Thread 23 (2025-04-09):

keycaps for iso layouts

tflori, 2025-04-09:
I'm planning a split keyboard with default ISO layout. while it was ok to just strech the keys to 1.5U I have an issue the enter key for ISO layouts.

my plan is to have a key with 18mm width on the bottom side of the key with 35mm height but the upper part (in the upper row) is 4.5mm wider.

I know there are many differences from keyboard to keyboard about how wide a enter key is but if we would have a key with the form we can at least strech the parts that we want to have wider..

currently i'm planning with this key:

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

braindefender, 2025-05-12:
Hi, keycaps for ISO and other strange forms are not planned.

Closed 2025-05-12.

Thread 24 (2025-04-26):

recommendations for jlc3dp printing material

SergioMG97, 2025-04-26:
Hey there, I really love the designs and I was thinking of printing a bunch of them in my next order to jlc3dp. Do you have any recomendation regarding the printing tehcnology and material, I like the of finish of the examples you published. I appreaciate any help because I'm so lost haha

braindefender, 2025-05-01:
Hi, I've never printed via JLC or any other third-party printing services.
I have both FDM and SLA printers at home, so I only used them.

So, there will be no direct recommendations. But I heard that white SLA on JLC is sun-sensitive and may gain yellow-orange tint over time.

peterjc, 2025-07-04:
I ordered the choc saddle set with JLCPLC this week, SLA resin, LC Black resin, defaults otherwise - after review both files gave:

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

and:

> Review Note:
> 1.Connected-design parts will requires more extra materials; more extra time in the post processing and package etc. So extra cost 0.1$/pcs will be charged. Also, the build time will add 1-2 more business days. For more details, please also visit our statements on the website below. Thanks ! https://jlc3dp.com/help/article/213-Connected-Parts-Printing-Guide

The price looks to have gone up by about $1 per set. Fingers crossed.

thrly, 2025-08-06:
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

What were the results? I've just made an order and got the same errors...

peterjc, 2025-08-06:
Thanks for the reminder - my JLCPLC resin prints turned out nicely.

They did seem to run into a QC issue with the keycaps through (I could login to the website and check progress - and one bundle of keycaps was clearly packaged after everything else):

> Thank you so much for ordering from JLCPCB, but we regret to tell you that your order XXX will be delayed due to some of the 3D-printing parts scrapped. It may take 2 more days to be redone/ re-manufactured for sufficient quantity for your order.

They could be removed from the choc switches much more easily than my MKB key caps (which I bought in the meantime).

Photos:

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

I’m currently using the MBK set, but will build a second keyboard… https://fediscience.org/@pjacock/114870433960368787

thrly, 2025-08-06:
@peterjc thanks! Ahh interesting that they're easier to remove than MBKs (what I'm looking to replace), does that imply the fit is less secure? Wonder if that's a material or a design thing...

fantaandcode, 2025-08-09:
I'd suggest using a little bit of Kapton tape. Adhere it to the keycap and it's easy to remove later too if need be.

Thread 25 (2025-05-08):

Semi-saddle profile

arialdomartini, 2025-05-08:
What I love the saddle profile is how it is convenient for fingers to slide from the home-row forward or backward to the upper or the lower line, like on a gentle rail.

The only exception I found is for my index fingers when they have to move from their natural column (VFR MJU on a QWERTY) to the inner column (BGT NHY).

Think to the 2 saddle borders on the right of H and the left of J

```
\___/ \___/ \___/ \___/ \___/
  H     J     K     L     ;
```

It would be nice if the borders was flat, so that the finger could more from J to H sliding.

```
\___. .___/ \___/ \___/ \___/
  H     J     K     L     ;
```

Given the symmetry, H and J can use the very same semi-saddle keycap, rotated by 180 degree.

I'm not good at CAD, so I am not sure I am able to send you a PR with such profile.

What do you think?

braindefender, 2025-05-08:
I think that is the reason why [CLP](https://github.com/vvhg1/clp-keycaps) keycaps have `Saddle Lower Side` and `Tilted Slanted` variants. It'll be good to have those on `TGB/YHN` columns. In addition, if the fingers are short enough, then moving the index finger to adjacent column results in the middle finger ending up on the edge of the keys (right on bumps). Maybe I'll consider it in the next updates.

arialdomartini, 2025-05-08:
(Just found out that https://github.com/vvhg1/clp-keycaps implemented a similar idea with the tilted+slanted keycaps. Unfortunately, they are only MX)

taropoo, 2025-07-17:
Along the lines of @arialdomartini 's request, I am wondering if @braindefender you'd consider making a less tilted version, like maybe 7 degrees? My use case is I have a lily58 layout, I am currently using saddle tilted for both first and second rows, it feels really nice to type second rows but not so much for the first row. Maybe I should just use regular saddle version for second rows 🤔

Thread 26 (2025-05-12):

Clarify the keycap sizes used under the Production folder

floating-cat, 2025-05-12:
Hi,

I am trying to print a keycap for lapka keyboard.
But it's unclear what size is used for keycaps under the Production folder.

Could you please add details about what size is used for [Production](https://github.com/braindefender/KLP-Lame-Keycaps/tree/master/Production)/MX/KLP_Lame_MX-Normal-4xNormal_Tilted-3xThumb-1xNormal_Homing-1xNormal-Combined.7z and KLP_Lame_MX-Normal-6xNormal_Tilted-3xNormal-Combined.7z？
Is it an MX stem with a Choc size or with an MX size?

braindefender, 2025-05-12:
Hi, inside the `Production` folder are standard versions: MX+MX / Choc+Choc.
Currently, there are no `Production` files for MX+Choc / Choc+MX variants.

I'll add them this week (probably) with a fix from #22

braindefender, 2025-07-04:
Hi, fixed by latest commit

Closed 2025-07-04.

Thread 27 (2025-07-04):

Would it be possible to release bigger caps?

andywarburton, 2025-07-04:
I really love these caps and I’m seriously considering them for my daily driver. Only problem is I use 2u keys in a couple of places and it would look weird with a single key or off-brand 2u with these beautiful caps.

I don’t know about everyone else but I would really love to see a 2u version (and maybe 1.5u) in the future.

Thank you again for designing and sharing these beautiful caps!

andywarburton, 2025-08-10:
I hacked together my own 2U key. You can find it in the remixes on Printables should anyone need it.

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

andywarburton, 2025-08-10:
@braindefender you are welcome to use this picture in your examples if you wish!

tarikkirgin, 2025-08-13:
This looks great, what material is it?

andywarburton, 2025-08-13:
It’s Anycubic ABS like resin in clear with some green dye added

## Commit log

2023-07-18 add more info
    [KLP_Lame_Keycaps.stl, KLP_Lame_Plain.stl, KLP_Lame_Thumb.stl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]
2023-08-11 Add Saddle version, add images and photos
    [KLP_Keycaps_Normal.f3z, KLP_Lame_Normal.stl, KLP_Lame_Plain.stl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]
2023-08-11 add Saddle Homing F3Z
    [KLP_Saddle_Homing.f3z]
2023-08-13 add STL for homing versions
    [KLP_Lame_Normal_Homing.stl, KLP_Lame_Saddle_Homing.stl]
2023-08-23 add MX version
    [KLP_Keycaps_Normal_MX.f3z, KLP_Keycaps_Tilted_MX.f3z, KLP_Lame_Normal.stl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]
2023-08-26 fix choc thumb
    [KLP_Lame_Thumb.stl]
2023-08-30 add combined STL for JLCPCB/PCBWay
2023-08-30 switch to Git LFS
    [KLP_Lame_Normal.stl, KLP_Lame_Normal_Homing.stl, KLP_Lame_Normal_Homing_MX.stl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]
2023-09-04 split combined STL for JLCPCB/PCBWay
    [KLP-Lame-18-keys-Normal-Combined.stl, KLP-Lame-18-keys-Saddle-Combined.stl, KLP-Lame-36-keys-Normal-Combined.stl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]
2023-09-04 split files again
    [KLP-Lame-18-keys-Normal-Combined.stl, KLP-Lame-18-keys-Saddle-Combined.stl, KLP-Lame-Normal-4NT-3TH-1NH-1N-Combined.stl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]
2023-10-29 feat: remove LFS, add MX Combined version, fix homing bumps
    [KLP_Lame_Normal.stl, KLP_Lame_Normal_Homing.stl, KLP_Lame_Normal_Homing_MX.stl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]
2023-11-16 fix: update new homing fusion files
    [KLP_Keycaps_Homing.f3z]
2024-11-07 feat: add chamfers; fix: changes photos
    [KLP_Keycaps_Homing.f3z, KLP_Keycaps_Normal.f3z, KLP_Keycaps_Normal_MX.f3z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]
2024-11-08 major: v1.1 version release
    [KLP_Lame_MX_Normal.stl, KLP_Lame_MX_Normal_Homing.stl, KLP_Lame_MX_Normal_Tilted.stl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]
2025-01-18 feat: add STEP files
    [KLP_Lame_MX_Normal.step, KLP_Lame_MX_Normal_Homing.step, KLP_Lame_MX_Normal_Tilted.step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]
2025-03-10 feat: add 90deg variant of choc keycaps
    [KLP_Lame_Normal_90deg.step, KLP_Lame_Normal_90deg.stl, KLP_Lame_Normal_Homing_90deg.step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]
2025-05-10 feat: add mix and match choc/mx variants
    [Choc_Stem_Choc_Size_Normal.step, Choc_Stem_Choc_Size_Normal.stl, Choc_Stem_Choc_Size_Normal_90deg.step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]
2025-07-13 major: v1.4 release
    [Choc_Stem_Choc_Size_Normal.step, Choc_Stem_Choc_Size_Normal.stl, Choc_Stem_Choc_Size_Normal_90deg.step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]
2025-11-16 major: v1.5u release
    [Choc_Stem_Choc_Size_1.5U_Normal.step, Choc_Stem_Choc_Size_1.5U_Normal.stl, Choc_Stem_Choc_Size_1.5U_Saddle_H.step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]
